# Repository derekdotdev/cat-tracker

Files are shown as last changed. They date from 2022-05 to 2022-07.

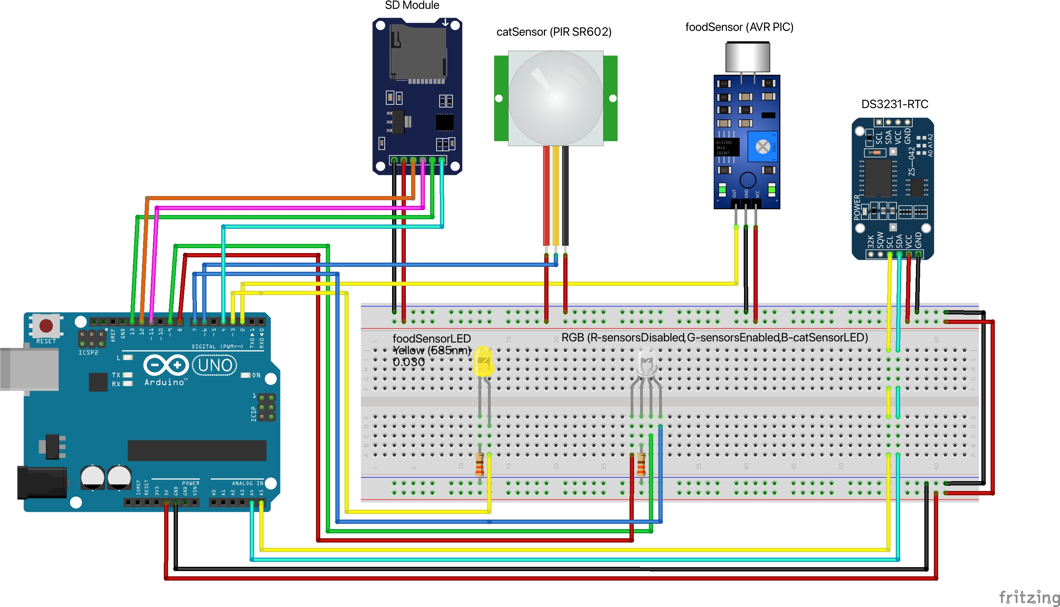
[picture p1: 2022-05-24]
Documentation/Schematics/JunoTracker5000FritzingSketch-SoundSensor_bb.jpg

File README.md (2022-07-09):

# cat-tracker
## An Arduino project which measures the time difference between my cat's automatic feeder dispensing food and him arriving at his bowl.

The task assigned for my senior project is to put together a small data collection system and visualize the data in a graphical manner.

Here's the [final presentation of the project](https://vimeo.com/726744707)

When brainstorming ideas one evening, my 15-pound cat Juno came in to let me know he was hungry. 

Now, I cut myself out of that equation *years ago* by getting him an auto-feeder, but he still insists on letting me know when it's dinner time.

What happened next was pure serendipity. The instant his feeder began to loudly dispense his food, he bolted out of the room faster than a bat out of hell!

It was then that I realized what I had to do....

## Introducing: The ~~Juno~~ Cat Tracker 5000

This feat of modern engineering is centered around an Arduino Uno Microcontroller which leverages the power of its ATMega328P to do the unthinkable.

The Cat Tracker 5000 uses the first of its **two** passive infrared (PIR) sensors to detect when your pet's food begins dispensing, and writes the 
foodEvent to a built-in SD card with a timestamp provided by its fully-programmable DS3231 real-time clock (RTC) module. 

When your pet arrives on the scene 2.2 seconds later to gobble down that hard-earned food, the second PIR sensor is triggered and the petEvent is also written to the SD.

###But wait..there's more!! 

The events are written to the SD card as comma-separated values (CSV) which can then be imported into your favorite spreadsheet program for analysis!

Pre-order this totally real product today!

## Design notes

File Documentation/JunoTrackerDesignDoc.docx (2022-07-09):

Juno Tracker 5000

Developer Documentation

Valencia College | Summer 2022

Derek DiLeo

# Document Updates

Revision ID | Date | Author | Notes
1.0 | 05/20/2022 | Derek DiLeo | Initial draft
1.2 | 06/08/2022 | Derek DiLeo | Complete 'Handling Data' Section using screen shots with test data
1.3 | 07/05/2022 | Derek DiLeo | Review and Submission

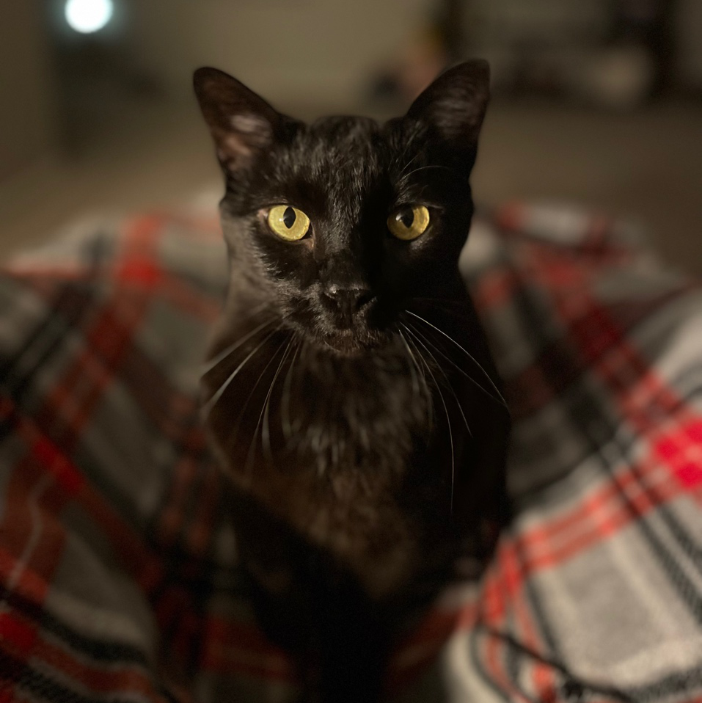
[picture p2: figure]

Table of Contents

# Introduction

This software project is focused on the concept of 'small data' to answer the age-old questions: "How quickly does my cat get to his food bowl after his auto-feeder begins dispensing his food? How can this data be collected and presented?"

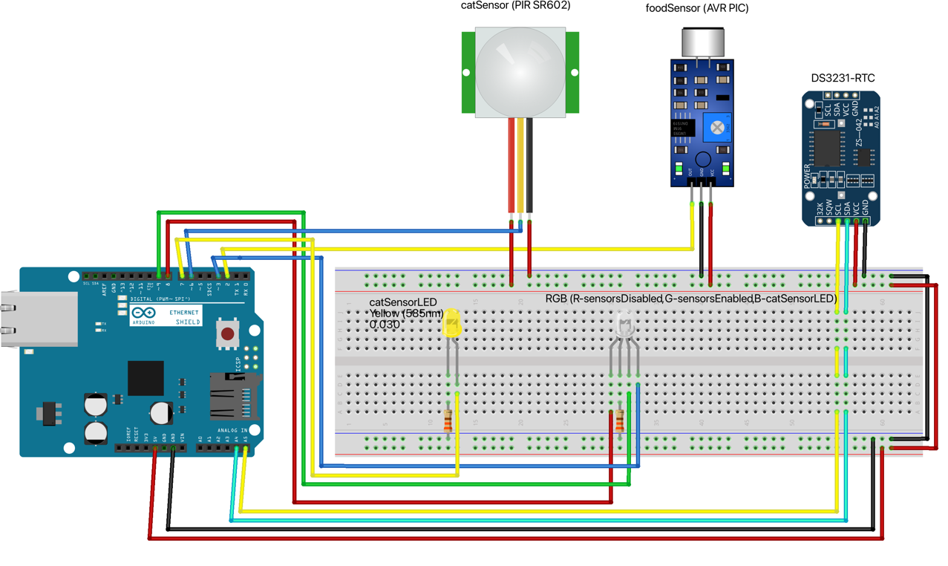
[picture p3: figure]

## Installation Guide:

1. Download the Arduino JunoTracker5000.ino sketch here (https://github.com/derekdotdev/cat-tracker). Notes:
  a. See repo for alternate circuit using UNO and SD Card Module
  b. You must update date and time in Initialize_RTC() function (line 215)
  c. You must update timeIsValid() function to match your pet's feeding time(s)
2. Assemble the circuit shown above (pins are outlined in comments at top of sketch).
3. Prepare your Micro SD card (https://learn.adafruit.com/arduino-ethernet-sd-card?view=all) for use with Arduino SD Library.
4. Carefully insert SD card into the slot.
5. Position sensors. foodSensor audio threshold calibration is required. Note: Both sensors are ignored outside 'feeding windows' set in step 1c and catSensor is ignored until foodSensor is triggered.
6. Install Arduino.app (https://www.arduino.cc/en/software) to your Applications folder.
7. Download the DS3231 RTC Module library (http://www.rinkydinkelectronics.com/download.php?f=DS3231.zip) from Rinky-Dink electronics and add to project with Sketch > Include Library > Add .ZIP Library...
8. Connect your Arduino to an available USB port. UNO rev3 with Ethernet Shield 2 is preferred, but any SD module will work if default Chip Select pin is considered.
9. Upload the sketch to your Arduino ~10 seconds before time set in step 1b (to account for delay() functions in setup() function) and let it do its thing!

# Overview

## Purpose

The goal of this project is to aid in better understanding the speed at which my cat, Juno, can run to his feeding bowl after it begins automatically dispensing a meal by collecting the time differences between two sensors being activated. The first is tripped when the food begins dispensing and the second is tripped when Juno arrives at his bowl. The comma-separated value (CSV) data is written to an SD card with a timestamp where it can later be imported into a spreadsheet for analysis (see Handling Data).

## Collecting Data

This application is programmed to run without the need to be connected to a computer and depending on the number of meals per day, can take some time to collect sufficient data. To allow the user to validate functionality without a UI, LEDs are incorporated to notify the user of the status. During startup, the RGB LED will illuminate GREEN for a period of four seconds and turn off to indicate that the setup function is complete. The RGB LED is also used to indicate the status of the sensors which are only programmed to be active for a six-minute 'feeding window' around each feeding time. These windows are used to mitigate false sensor events from being recorded and to allow for slight time differences between the auto-feeder and RTC module. When they are active, the RGB will glow GREEN and when inactive, it will glow RED. The RGB will also glow BLUE when the catSensor is tripped. This, however, can only occur once the foodSensor has been triggered which is indicated by the YELLOW LED. To recap:

RGB glows GREEN at startup for 4 seconds to indicate program setup is complete

RGB glows RED while outside of 6-minute feeding window (3-min before / after)

RGB glows GREEN once inside 6-minute feeding window (until foodSensor trips)

When foodSensor is tripped:

- RGB RED and GREEN LEDs are disabled
- RGB YELLOW LED glows for 500ms and turns off
- Current time (in ms) is saved to foodTime variable
- At this point, all LEDs remain off until second sensor trips

When catSensor is tripped:

- RGB glows BLUE until motion is no longer detected
- foodTime (and LED delays) subtracted from current time to get responseTime
- Date, Time, and responseTime are written to SD card as CSV

Finally:

- RGB is set to glow RED again
- A 30-minute (1800000 millisecond) delay is set to avoid repeat sensor event data during current feeding window
- The process repeats

## Handling Data

Once a reasonable amount of data has been collected, it is time for analysis. Feel free to follow the steps below or watch a video tutorial here (https://www.youtube.com/watch?v=EDtZcM9CFKY). Unplug the Arduino, carefully eject the SD card and insert into a card reader attached to your computer. Locate the file LOGGERCD.TXT on the SD and open it in a preferred text editor.

Each time the program starts and Initialize_SDcard() runs, the first line of the data file is written which, if multiple exist, can affect our import. To avoid any issues, remove all test data prior to the final write of the first row. Your data should resemble the following:

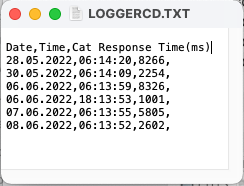
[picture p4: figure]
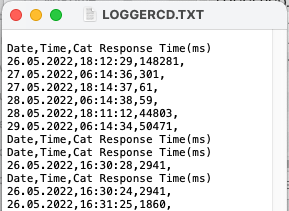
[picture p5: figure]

Figure 1 - Before Test Data Removal

Figure 2 - After Test Data Removal

Open a new Excel spreadsheet, navigate to the Data tab, and select Get Data from Text and choose the updated LOGGERCD.TXT from the SD in the Get Data dialogue.

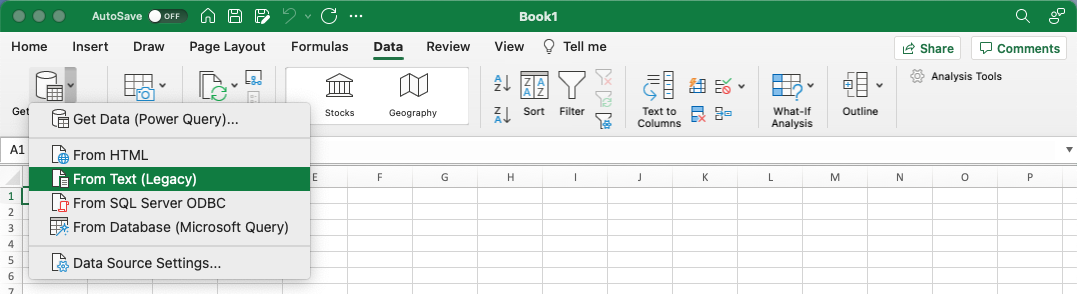
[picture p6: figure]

Figure 3 - Get Data From Text (Legacy)

Navigate the Text Import Wizard:

Step 1: Select Delimited and Click Next

Step 2: Select Comma and Click Next

Step 3: Select 'Date', change to DMY to set correct Date format, and click Finish

Step 4: Import Data to Existing sheet at =$A$1

The following screenshots will serve as a guide to navigate the Text Import Wizard.

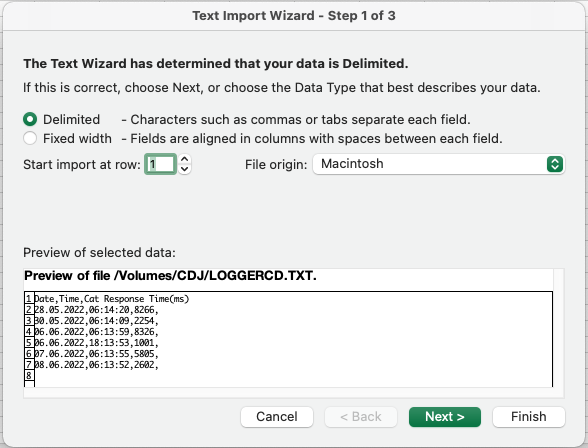
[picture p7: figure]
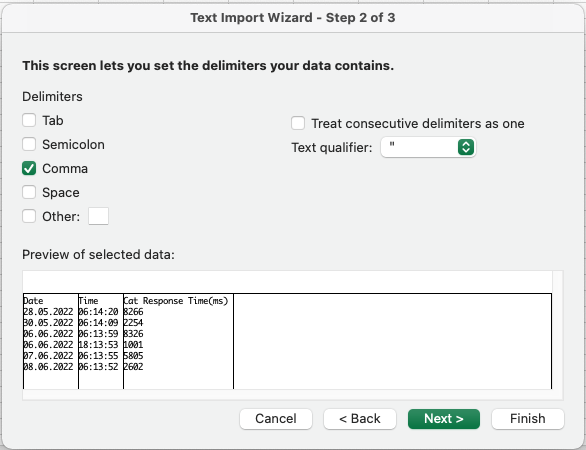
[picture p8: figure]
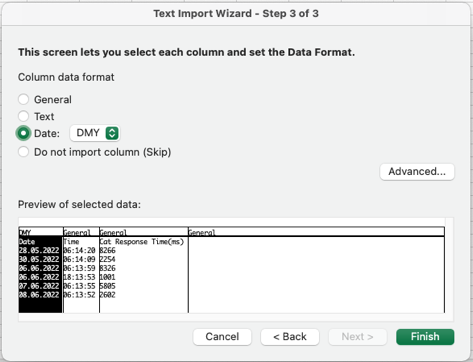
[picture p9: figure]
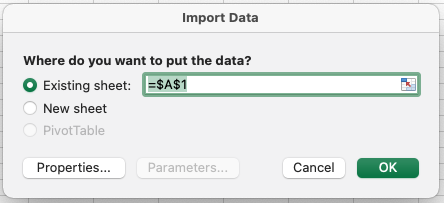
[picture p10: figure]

Figure 4 - Navigate the Text Import Wizard Steps 1-4

Calculate SUM and AVERAGE Values:

Step 1. Select the next empty cell below the list of times

Step 2. Navigate to Formulas tab and select Sum

Step 3: Press Enter

Step 4: Select the next empty cell below the list and repeat for Average

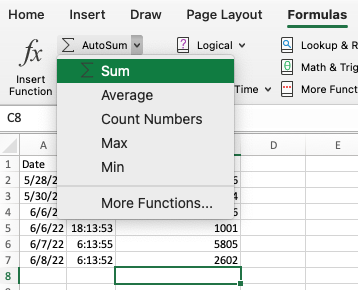
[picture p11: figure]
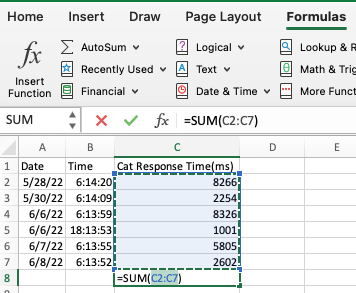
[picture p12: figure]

Figure 5 - Calculate Sum and Average Response Time

Graph Results:

Select all rows and columns, navigate to Insert tab, and select a 2-D Column Bar Graph

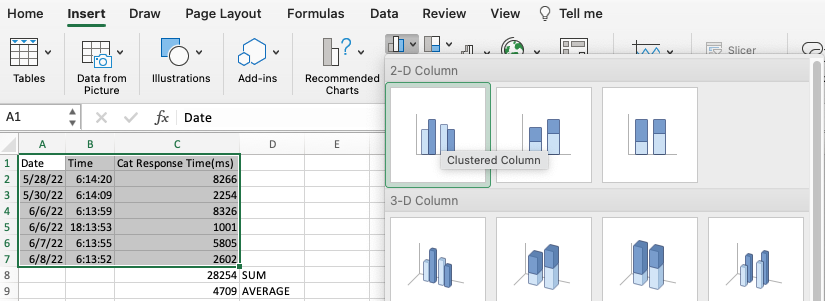
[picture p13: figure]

Figure 6 - Insert a 2-D Bar Graph to Display the Results

# Conclusion

## Hardware

Photos of the system once fully operational.

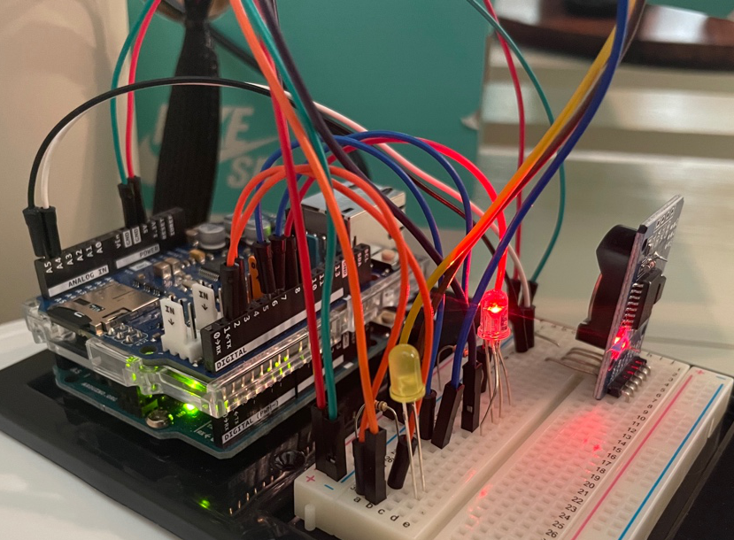
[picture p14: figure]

Figure 7 - Circuit Overview

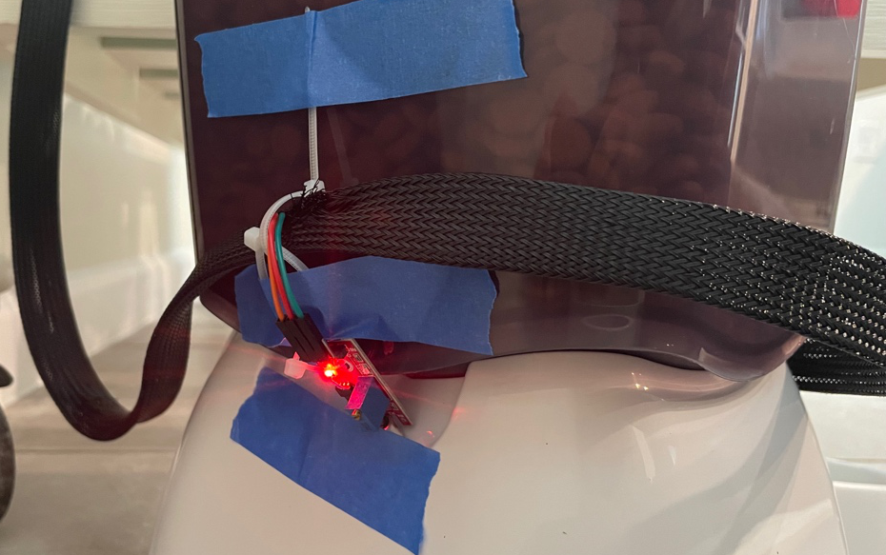
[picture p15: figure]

Figure 8 - AVR Sound Sensor Placed Directly on Body of Auto-Feeder

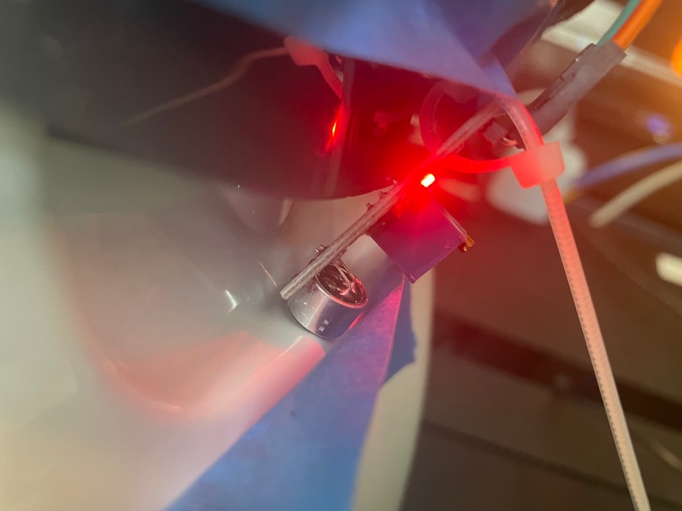
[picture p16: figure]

Figure 9 - AVR Sound Sensor Placed Directly on Body of Auto-Feeder (close)

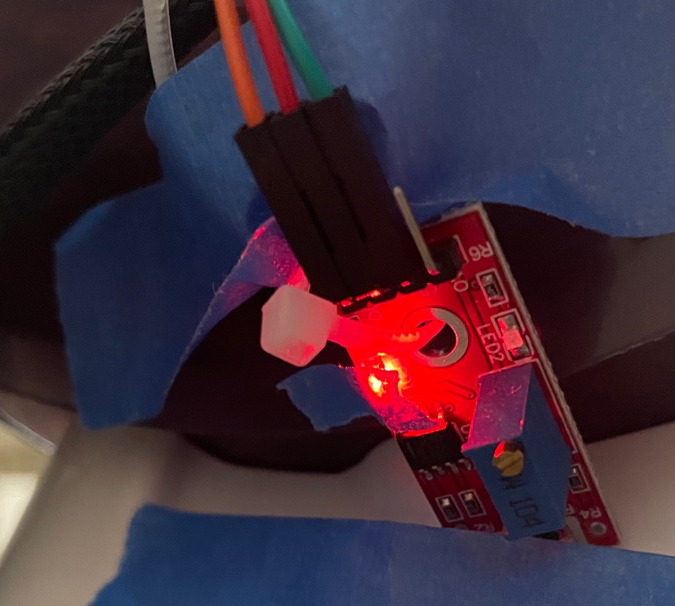
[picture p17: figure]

Figure 10 - AVR Sound Sensor Placed Directly on Body of Auto-Feeder (close)

## Results

After one month, the following data about Juno's response time was captured.

Minimum: 1001ms (GREEN)

Maximum: 8326ms (RED)

Average: 2958ms (YELLOW)

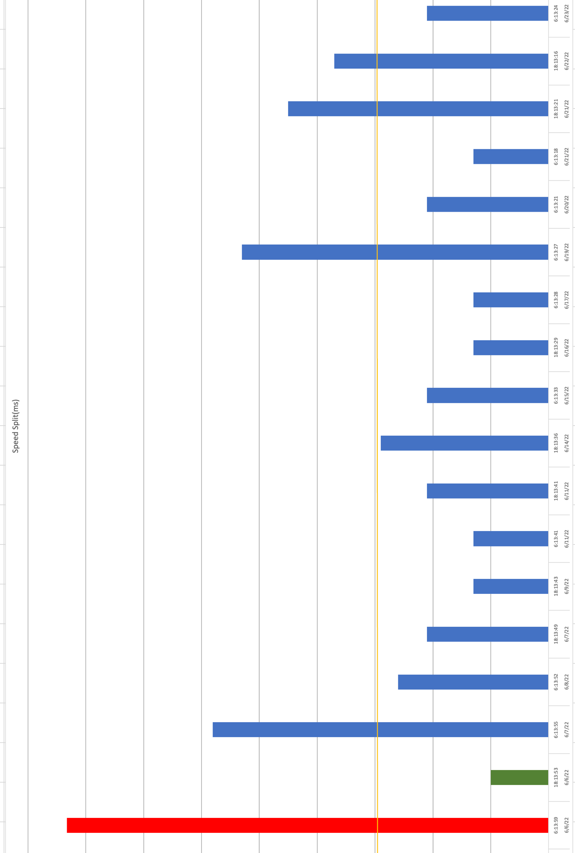
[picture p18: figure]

Figure 11 - Results Graph

## Conclusion

The Juno Tracker 5000 project was more difficult to implement than initially expected, but it turned out to be a great learning experience for many reasons. First, where the concepts of requirements gathering, and research intersect is where one can attain the most insight about the overall cost and schedule of the project. If I had conducted more thorough research up front, I would have known that PIR sensors are not ideal for capturing dry cat food in motion and, thus, avoided the additional cost and timeline delays that were introduced by purchasing the AVR sound sensor. Second, because the data were written to an onboard SD card, the only feedback from the device while it was deployed was from a couple of onboard LED indicators. Without access to the data in real time, I was essentially blind to the performance and overall status of the device. If I could start this project over, I would set up a local network server and database and connect the Arduino to it so the data could be accessed whenever without worry of taking the device offline. Lastly, I discovered that the more interest I took in Juno's feeder, the closer he would be to it at mealtime. Some data had to be deleted because his response time was essentially instant since he was sitting right next to it when it began dispensing food.

Overall, this was a fun project and an awesome way to collect 'small data'. Some people want a 10-second muscle car, but I've got a 3-second cat!! Please follow this link to see the full project presentation (https://vimeo.com/726744707). Thanks for reading!!

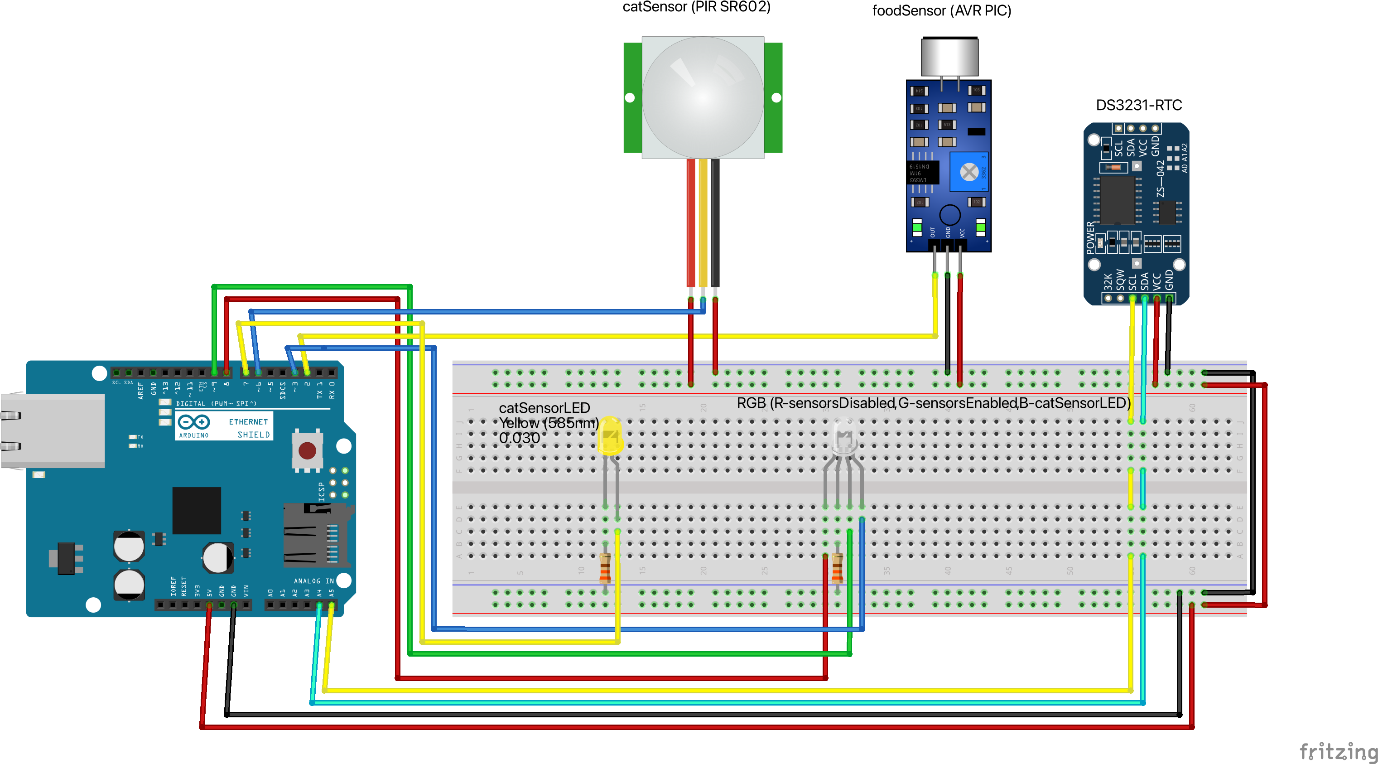
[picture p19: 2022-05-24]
Documentation/Schematics/JunoTracker5000FritzingSketch-EthernetShield-SoundSensor_bb.png

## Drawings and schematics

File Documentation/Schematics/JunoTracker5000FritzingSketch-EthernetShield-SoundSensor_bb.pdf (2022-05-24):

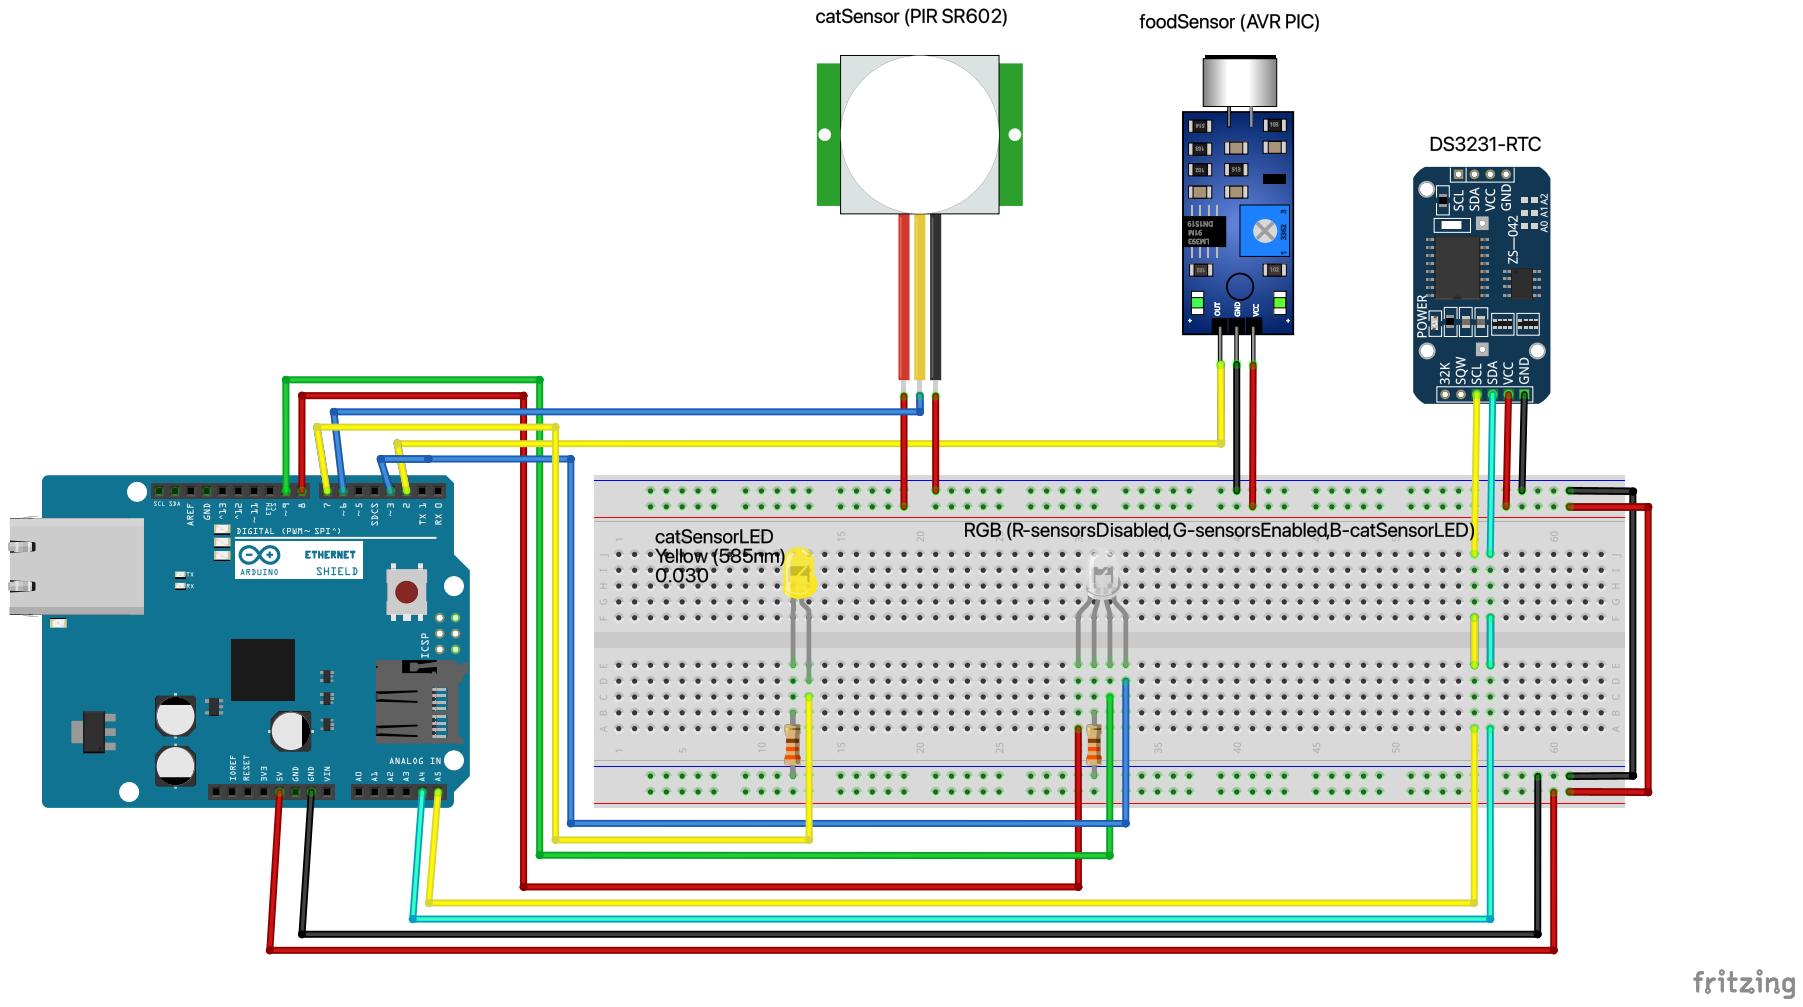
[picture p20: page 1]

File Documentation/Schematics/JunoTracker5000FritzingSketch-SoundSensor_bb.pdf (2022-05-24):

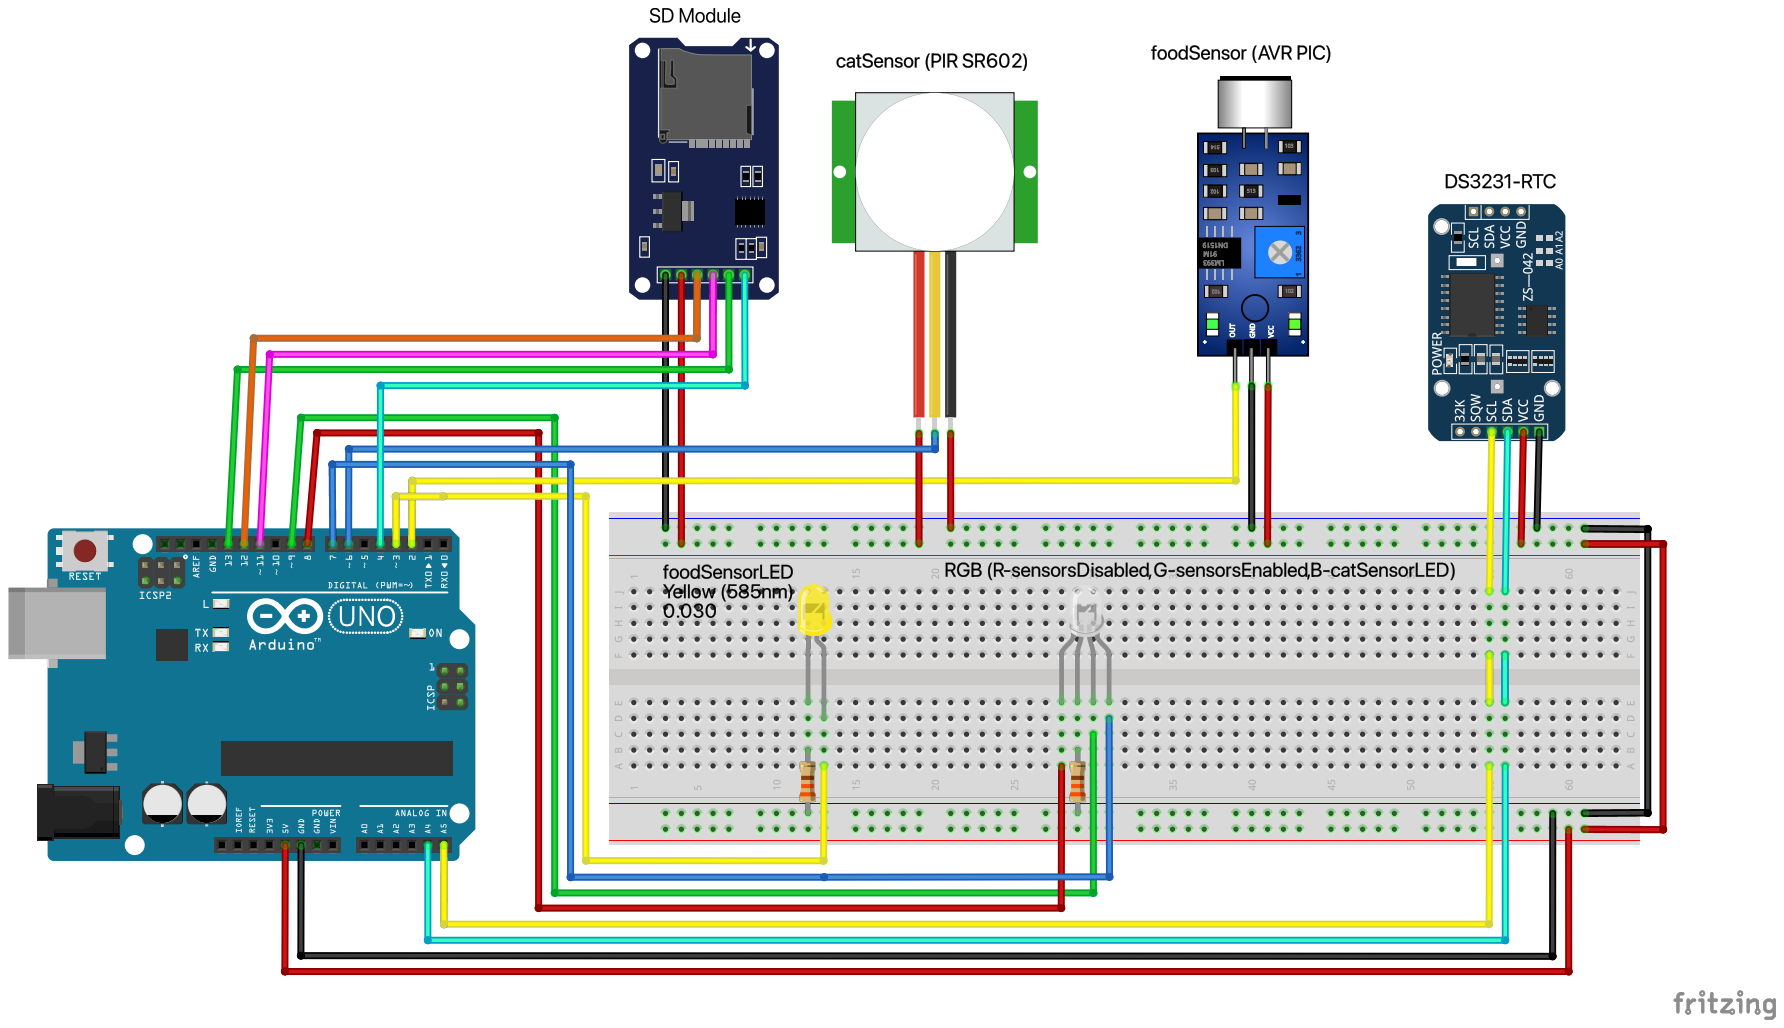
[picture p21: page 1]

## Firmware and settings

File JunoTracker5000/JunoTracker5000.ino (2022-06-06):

/*
    C Program for Arduino to demonstrate how to collect 'small data' to see how quickly my cat can run.

    This example uses two PIR sensors to track:
  - When my cat's auto feeder begins dispensing a meal
  - When my cat arrives at his bowl to eat (he DARTS to the kitchen as soon as he hears it)

   Finally, these events are timestamped and saved to an SD card as a CSV for further analysis. ----

    ### - The Circuit - ###

    ### Multi-purpose RGB LED ###

      (cathode)     ->  330 Ohm -> GND
      (Red anode)   ->  pin 8 [Sensors Disabled]
      (Green anode) ->  pin 9 [Power ON & Sensors Enabled]
      (Blue anode)  ->  pin 7 [Cat Sensor Indicator]

    ### Food Sensor LED ###
      (cathode)     ->  330 Ohm -> GND
      (anode)       ->  pin 3 [Food Sensor Indicator]

    ### SD Card (built into Arduino Ethernet Shield 2) ###
    SDO -> pin 11

    SDI -> pin 12

    CLK -> pin 13

    CS -> pin 4

    ### DS3231 Real Time Clock (RTC) Module ####
    VCC -> 5V

    Gnd -> Gnd

    SCL -> pin A5

    SDA -> pin A4

    ### PIR SR602 Sensor (foodSensor) ###
    VCC -> 5V
    Gnd -> Gnd
    Signal -> pin 2

    ### PIR SR602 Sensor (catSensor) ###
    VCC -> 5V
    Gnd -> Gnd
    Signal -> pin 6

    Imagined: 16 May 2022
    Created:  19 May 2022

    by Derek DiLeo

    This code is in the public domain

*/

#include <DS3231.h>        // Library for RTC module (Downloaded from RinkyDink Electronics)
#include <SPI.h>           // Library for SPI communication (Pre-Loaded into Arduino)
#include <SD.h>            // Library for SD card (Pre-Loaded into Arduino)

DS3231  rtc(SDA, SCL);        // Init the DS3231 using the hardware interface

bool foodDispensed = false;    // catSensor only important if this is true

const int foodSensor = 2;            // the pin that the food sensor is attached to
const int foodLED = 3;               // the pin that the foodLED is attached to
const int chipSelect = 4;      // SD card CS pin connected to pin 4 of Arduino
const int catSensor = 6;             // the pin that the cat sensor is attached to
const int catLED = 7;                // the pin that the catLED is attached to
int foodSensorState = LOW;     // by default, no motion detected
int catSensorState = LOW;      // by default, no motion detected
int foodSensorVal = 0;         // variable to store the food sensor status (value)
int catSensorVal = 0;          // variable to store the cat sensor status (value)

// variable to store millis() when food drops and is later
// subracted from catSensor time to determine cat's reaction speed
unsigned long foodTime;

/*****************************************************************************************************
   Setup
    - Open Serial connection
    - Set input/output pins
 *****************************************************************************************************/
void setup() {

  Serial.begin(9600);            // initialize serial (USB) connection

  delay(2000);
  // wait for Serial Monitor to connect. Needed for native USB port boards only:
  while (!Serial);

  Serial.print("Initializing RTC...");

  Initialize_RTC();

  delay(2000);

  Serial.println("Initializing SD card...");

  Initialize_SDcard();

  Serial.println("initialization done.");

  // initialize program started / sensors enabled LED
  pinMode(9, OUTPUT);
  pinMode(8, OUTPUT);            // initialize sensors disabled LED
  digitalWrite(9, HIGH);         // indicate setup() running

  pinMode(foodLED, OUTPUT);      // initalize foodLED as an output
  pinMode(foodSensor, INPUT);    // initialize foodSensor as an input
  pinMode(catLED, OUTPUT);       // initalize catLED as an output
  pinMode(catSensor, INPUT);     // initialize catSensor as an input

  delay(4000);                   // wait 4 seconds
  digitalWrite(9, LOW);          // turn off LED to indicate setup() done


}

/*****************************************************************************************************
   Loop
    - Check sensors for movement
    - When foodSensor is tripped, write event with timestamp to SD
    - If catSensor is tripped after foodSensor, write event with timestamp to SD
 *****************************************************************************************************/

// TODO: Figure out how to avoid false and repeat sensor trips.
// We only want ONE trigger per meal and do not want Roomba or Juno licking bowl(yes, he does that) to
// trigger a false sensor event. (timer?)
// TODO: Set up and test with actual food dispenses
void loop() {

  foodSensorVal = digitalRead(foodSensor);   // read foodSensor value
  catSensorVal = digitalRead(catSensor);     // read catSensor value

  if (timeIsValid()) {
    // Indicate within feeding window
    digitalWrite(9, HIGH);  // GREEN
    digitalWrite(8, LOW);   // RED

    if (foodSensorVal == HIGH && !foodDispensed) {   // check food being dispensed for first time
      // turn off sensor indicator LEDs so foodLED and catLED are more pronounced
      digitalWrite(9, LOW);
      digitalWrite(8, LOW);

      digitalWrite(foodLED, HIGH);             // turn foodLED ON
      delay(500);                              // delay 500 milliseconds

      if (foodSensorState == LOW) {
        Serial.println("Motion Detected on Food Sensor!");

        foodDispensed = true;

        foodTime = millis() - 500;                  // Capture current time (minus LED delay)

        foodSensorState = HIGH;                // update foodSensorState to HIGH
      }
    } else {
      digitalWrite(foodLED, LOW);            // turn foodLED OFF

      delay(300);                            // delay 300 milliseconds

      if (foodSensorState == HIGH) {
        //      Serial.println("Food Sensor Motion stopped!");
        foodSensorState = LOW;               // update foodSensorState to LOW
      }
    }

    // check catSensor motion and food dispensed
    if (catSensorVal == HIGH && foodDispensed) {
      digitalWrite(catLED, HIGH);            // turn catLED ON

      delay(500);                            // delay 500 milliseconds

      if (catSensorState == LOW) {

        Write_SDcard((millis() - foodTime - 800));  // Write split time SD (compensate for LED delays)

        catSensorState = HIGH;               // update catSensorState to HIGH
      }
    } else {
      digitalWrite(catLED, LOW);             // turn catLED OFF

      delay(500);                            // delay 500 milliseconds

      if (catSensorState == HIGH) {
        catSensorState = LOW;                // update catSensorState to LOW

        foodDispensed = false;               // reset foodDispensed

        digitalWrite(8, HIGH);               // Set RED LED to HIGH to indicate sensors disabled

        // Pause program for 30 minutes to avoid multiple writes
        delay(1800000);

      }
      
    }

  } else {
    digitalWrite(9, LOW);   // GREEN
    digitalWrite(8, HIGH);  // RED
  }

}

/*****************************************************************************************************
   timeIsValid
    - This function is used to prevent false data entry by checking current time against
        set times when his food is dispensed (6:15 & 18:15)
    - Reasons: Juno likes to lick his bowl when he's hungry (all the time)
        and his food bowl is near the Roomba dock.
 *****************************************************************************************************/
bool timeIsValid() {

  int hourNow = rtc.getTime().hour;         // Get current hour
  int minuteNow = rtc.getTime().min;        // Get current minute

  if ((hourNow == 6  || hourNow == 18) && (minuteNow >= 13 && minuteNow <= 18)) {

    return true;

  } else {

    return false;

  }

}


/*****************************************************************************************************
   Initialize_RTC
    - Initialize the RTC object
    - Set date, if needed
 *****************************************************************************************************/
void Initialize_RTC() {

  rtc.begin();           // Initialize the rtc object

  //#### The following lines can be [un]commented to set the current date and time###

  rtc.setTime(12, 19, 30);     // Set the time (HH:mm:ss) (24hr format)

  Serial.print("     Time read from rtc: ");
  Serial.print(rtc.getTimeStr());


  Serial.print("\nSetting date to 5/23/2022: ");

  rtc.setDate(6, 06, 2022);   // Set the date to May 5th, 2022

  Serial.print("   Date read from rtc: ");
  Serial.print(rtc.getDateStr());
  Serial.println(" ");
}

/*****************************************************************************************************
   Initialize_SDcard
    - Check if SD card is present and can be initialized (if not, return)
    - Open a new file on the SD card and write first row of excel file
 *****************************************************************************************************/
void Initialize_SDcard() {

  // check if the card is present and can be initialized:
  if (!SD.begin(chipSelect)) {

    Serial.println("Card failed, or not present");

    Serial.println("1. is a card inserted?");

    Serial.println("2. is your wiring correct?");

    Serial.println("3. did you change the chipSelect pin to match your shield or module?");

    Serial.println("Note: press reset or reopen this serial monitor after fixing your issue!");

    while (true);

  }

  // open the file. (note: only one file can be open at a time,

  // so you have to close this one before opening another).

  File dataFile = SD.open("LoggerCD.txt", FILE_WRITE);

  // if the file is available, write to it:
  if (dataFile) {

    dataFile.println("Date,Time,Cat Response Time(ms)"); //Write the first row of the excel file

    dataFile.close();

  }

  Serial.println("Initialize_SDcard() complete!");

}

/*****************************************************************************************************
   Write_SDcard
    - whichSensor is used to indicate if writing data about foodSensor or catSensor
    - isFood determines whether '0' or catTime-foodTime (in millis()) is written to CSV
    - Open the file on SD (if available)
    - Write date,whichSensor,currentTime & splitTime to CSV
 *****************************************************************************************************/
// void Write_SDcard(long foodDropTime) {
void Write_SDcard(unsigned long timeDiff) {

  // open the file. note that only one file can be open at a time,

  // so you have to close this one before opening another.

  File dataFile = SD.open("LoggerCD.txt", FILE_WRITE);

  // if the file is available, write to it:

  if (dataFile) {

    Serial.println("Cat sensor caused Write_SDcard call!");

    dataFile.print(rtc.getDateStr()); //Store date on SD card

    dataFile.print(","); //Move to next column using a ","


    dataFile.print(rtc.getTimeStr()); //Store time on SD card

    dataFile.print(","); //Move to next column using a ","


    dataFile.print(String(timeDiff));    // Store food dispense time - cat arrival time to SD card

    dataFile.print(","); //Move to next column using a ","


    dataFile.println(); //End of Row move to next row

    dataFile.close(); //Close the file

  }

  else

    Serial.println("OOPS!! SD card writing failed...\nFile not available!");

}

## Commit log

2022-05-20 Use millis() to track when food dispenses and when cat arrives. Write 0 to new fourth column in CSV file for the former and time difference for the latter.
2022-05-20 Update schematic comments at SOF.
    [JunoTracker5000FritzingSketch.fzz]
2022-05-20 Modify code to work with just sensors and SD until RTC arrives.
2022-05-21 Update code to accommodate RTC module which arrives today. Add comments and code in prep for when testing is finished (and only catSensor trips will be written to SD).
    [JunoTracker5000FritzingSketch.fzz]
2022-05-22 Add DS3231 to circuit and code. Add timeIsValid function (will be implemented later) to only allow sensor trips to record data if during feeding times.
2022-05-22 Add 11 hour timer (delay(39600000)) after catLED goes LOW to prevent multiple events from being written during a feeding.
    [JunoTracker5000.ino]
2022-05-22 Updated RTC initialization so time will be accurate when powered on in the kitchen for the first round of tests.
2022-05-22 Add power LED pins to comments at top of sketch. Add Fritzing Circuit Images.
    [JunoTracker5000FritzingSketch-EthernetShield.fzz]
2022-05-23 Add minute validation to isTimeValid function to limit sensor arm times to 10 minutes (between 6:10 and 6:20). Add LED indicators for sensor armed status and update Fritzing Sketches. Update program 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
    [JunoTracker5000FritzingSketch-EthernetShield.fzz, JunoTracker5000FritzingSketch.fzz]
2022-05-23 Use pinMode(8, OUTPUT) in setup() for sensors not armed LED
2022-05-24 Update code and fritzing circuits to accommodate AVR PIC sound sensor detector to replace foodSensor PIR.
    [JunoTracker5000FritzingSketch-EthernetShield-SoundSensor.fzz, JunoTracker5000FritzingSketch-SoundSensor.fzz]
2022-05-26 Updated print statement for food sensor (which is now a sound sensor instead of PIR). Updated date time for RTC (battery not keeping time when powered down?).
    [JunoTracker5000FritzingSketch-EthernetShield-SoundSensor.fzz]
2022-05-29 Lengthen LED delays to 150ms and add 300ms to split time written to card to account for 2x150ms in delays. Add if check on foodDispensed for RED and GREEN LEDs within feeding window to prevent interr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
    [JunoTracker5000.ino]
2022-06-06 Increase LED delay times to ensure indicators are spotted when lit. Compensate for these times by subtracting when written to SD.
2022-06-08 Remove older JunoTracker sketch to avoid confusion. Add additional sketch with disabled feeding windows to allow for easier sensor testing and calibration.
    [JunoTracker5000-SensorTests.ino]
2022-07-09 Create folder for Fritzing schematics and documentation. Add design doc, powerpoint and final presentation video.
    [JunoTracker5000FritzingSketch-EthernetShield-SoundSensor.fzz, JunoTracker5000FritzingSketch-EthernetShield.fzz, JunoTracker5000FritzingSketch-SoundSensor.fzz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]
